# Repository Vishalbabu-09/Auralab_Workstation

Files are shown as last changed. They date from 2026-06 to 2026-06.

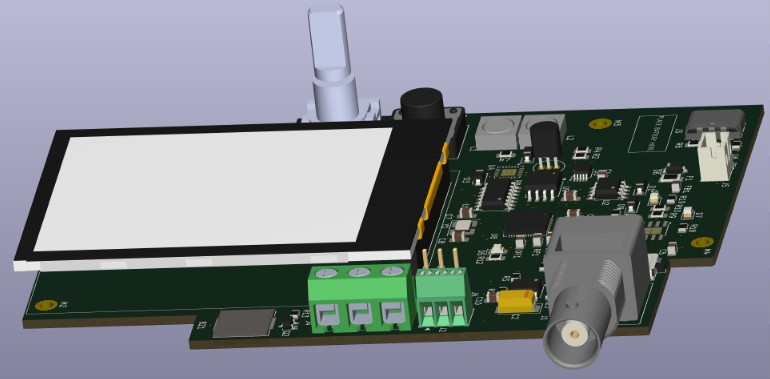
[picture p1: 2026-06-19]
Auralab_Workstation/Auralab_Workstation Images/Auralab Workstation 3D Sideview1.jpg

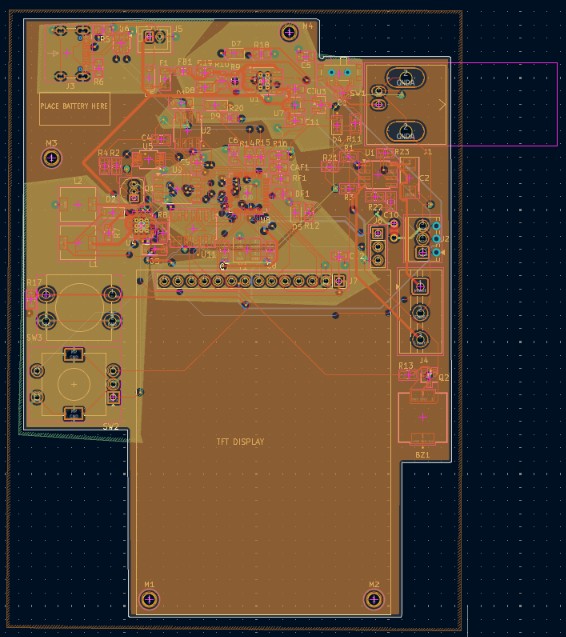
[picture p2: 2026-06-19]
Auralab_Workstation/Auralab_Workstation Images/4 Layers(F.Cu, In1.Cu, In2.Cu, B.CU).jpg

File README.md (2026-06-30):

# AURALAB WORKSTATION: Pocket-Sized Lab Bench & Hardware Diagnostic Toolkit

An advanced, ultra-portable multi-function test, measurement, and diagnostic platform engineered for the **KiCad PCB Design Contest**.

The **Auralab Workstation** packs a 12-bit digital oscilloscope, a variable bipolar $\pm15\text{V}$ bench power supply, an automated component curve tracer, and a smart hardware safety fault interrupter into a highly integrated, pocket-sized form factor.

---

## 1. System Working Modes & Operational Logic

The workstation utilizes the dual-core architecture of the **RP2040 microcontroller** to handle high-speed telemetry ingestion on one core while managing the graphical user interface (UI) and safety control loops on the second core.

### 📈 Mode 1: Oscilloscope Mode
* **What it does:** Captures, visualizes, and measures high-frequency external electrical signals in real time directly on the integrated 2.4" TFT display.
* **How it works:** Raw signals pass through an AC/DC coupling selector switch into a high-impedance **TL072 JFET operational amplifier** buffer circuit. This prevents the workstation from loading down the circuit under test. The conditioned signal is digitized by a dedicated **MCP3201 12-bit SAR ADC** operating over a high-speed SPI bus. Core 0 of the RP2040 processes the raw data arrays to compute signal parameters including **frequency, duty cycle, time period, $V_{pp}$ (peak-to-peak), and $V_{RMS}$**.

### ⚡ Mode 2: Bipolar DC Bench Power Supply Mode
* **What it does:** Acts as a precision-adjustable split-rail power supply delivering up to $\pm15\text{V}$ to drive external analog, op-amp, and prototype circuits via low-impedance screw terminals (`J2`).
* **How it works:** The user rotates the incremental digital encoder to set a target voltage. The RP2040 transmits this target via SPI to an **MCP42010 Dual Digital Potentiometer**. This digital pot dynamically alters the resistor feedback network of a high-efficiency **TPS65131 split-rail buck-boost regulator**, scaling the outputs symmetrically.

### 📊 Mode 3: Automated Component Curve Tracer Mode
* **What it does:** Plots the characteristic Voltage vs. Current ($V\text{-}I$) curves of un-biased two-terminal components (diodes, transistors, resistors, LEDs) directly onto the display to identify unknown parts or detect faulty silicon behavior.
* **How it works:** The workstation generates an internal hardware voltage sweep using a smoothed, high-frequency **Sweep PWM signal**. This low-pass filtered signal is amplified through a dedicated stage of the **TL072 op-amp**. As the voltage sweeps across the test terminal, an **INA219 high-side current monitor** reads the voltage drop across a $0.1\Omega$ shunt resistor, graphing the exact threshold voltages ($V_{th}$), saturation curves, and breakdown regions.

### 🛑 Mode 4: Smart Fault Detection & Overload Interrupter
* **What it does:** Acts as a real-time, hybrid hardware-software circuit breaker protecting both the workstation and your external device under test from short circuits, overcurrent conditions, and reverse polarity.
* **How it works:** The **INA219 current sensor** constantly monitors active current draw. If the current spikes past a safe user-defined ceiling, a hardware interrupt flag (`CURRENT_ALERT`) fires. The microcontroller instantly isolates the output terminals, flashes a high-intensity **ALERT_LED**, and triggers a resonant **Piezo Buzzer** to notify the user. Backup physical protection is maintained via an inline **Polyfuse (F1)** and steering clamping diodes.

---

## 2. Advanced 4-Layer PCB Stackup & Plane Allocation

To preserve 12-bit ADC accuracy while operating high-frequency digital clocks right next to high-gain analog buffers, this board utilizes a strict 4-layer mixed-signal stackup.

| Layer | Name | Copper Type | Main Signals & Plane Assignments |
| :--- | :--- | :--- | :--- |
| **Layer 1** | `F.Cu` (Top) | Signal / High-Speed | Component placement, SPI buses (Display, Flash, ADC), $\text{I}^2\text{C}$ lines, and sensitive analog trace lines. |
| **Layer 2** | `In1.Cu` | Split Ground Plane | **`GND` (Digital Ground Plane)** under the RP2040/Flash, and **`GNDA` (Analog Ground Plane)** under the Op-Amp/ADC/Reference. Isolated by a physical gap and joined strictly at a single point via a `NetTie_2` footprint near the power entrance. |
| **Layer 3** | `In2.Cu` | Dedicated Power Plane | Solid **`+3V3_DIGITAL`** power plane to provide clean, low-impedance power distribution across the digital logic core. |
| **Layer 4** | `B.Cu` (Bottom) | Signal Layer | Dedicated strictly to routing low-frequency control signals (Encoder pins, switch tracking lines) to keep them isolated from high-speed loops. |

---

## 3. Detailed Schematic & Hardware Architecture Breakdown

The hardware layout is organized into three highly optimized hierarchical sheets:

### 🔋 Module 1: Power Management & Filtration (Sheet 2)
Handles the regulation of raw input vectors, lithium-ion battery management, and high-current variable power rails.
* **USB-C Interface (`J3`):** Employs a 16-pin USB-C receptacle protected by an ultra-low capacitance **USBLC6-25C6 ESD array** to prevent electro-static damage across the differential lines.
* **BMS Stage (`U8`):** Uses a **TP4056 linear charger** with a precision $1.2\text{k}\Omega$ $R_{prog}$ resistor to regulate charging cycles safely for an attached Li-Po battery.
* **Split-Rail Engine (`U5`):** The **TPS65131 buck-boost converter** functions alongside high-current **SRR6048** power inductors ($L1, L2$) and high-speed Schottky catch diodes to cleanly establish the variable bipolar tracking rails.

### 🧠 Module 2: RP2040 Core & Interface Subsystem (Sheet 3)
Formulates the digital brain, memory maps, and human-machine interface routing.
* **Clocking Engine (`Y1`):** A low-jitter **12MHz Quartz Crystal** ensures ultra-stable operation for synchronous SPI data ingestion from the high-resolution ADC.
* **Storage Array (`U11`):** A **W25Q128JVS 128Mb QSPI Flash IC** stores custom GUI frames, display fonts, and analytical logging tables.

### 🔬 Module 3: Precision Analog Front-End (Sheet 4)
Handles conditioning, front-end buffering, clamping, and current telemetry tracking.
* **Precision Voltage Reference (`U3`):** Uses a low-drift **REF3033 bandgap voltage reference** to output a rock-solid, noise-free $3.3\text{V}$ absolute ceiling (`Vref_ADC`) directly to the SAR ADC, completely mitigating reference measurement drift.
* **Dynamic Range Shifter (`Q1`):** Features an automated hardware range shifter. By steering the gate of an **85170 N-Channel Power MOSFET**, the microcontroller alters the shunt resistor topology dynamically, switching scales between high-current tracking and micro-amp precision modes automatically.

---

## 4. Manufacturing & STEP Mechanical Export Validation

The project layout files have passed full Design Rule Checking (DRC) with 0 errors. A universal 3D mechanical master assembly model has been generated directly from the layout engine:

* **Export Format:** STEP (.step) standard mechanical vector.
* **Output Package Verified:** `Auralab_Workstation_Vishal.step` includes fully rendered 3D models for all high-profile custom footprints, including the 2.4" TFT module, the **XY126-3P** green terminal blocks, and the shielded **SRR6048** power inductors.
* **Compatibility:** Fully compliant with industry standard CAD software (SolidWorks, Autodesk Fusion 360, and free web viewers like `viewer.autodesk.com`).

---

## 5. Repository Directory Tree

```text
├── 3D Models Auralab_Workstation_Vishal/  <- Local STEP structural component cache
├── Auralab_Workstation Images/            <- Visual project logs and board renderings
├── Auralab_Workstation_Vishal schematic/  <- Schematic sheet files
├── Manufacturing/
│   ├── Drill/                             <- NC Drill files (.drl)
│   └── Gerbers/                           <- RS-274X Production plots (.gbr)
├── Auralab_Workstation_Vishal.kicad_pro   <- Master KiCad Project Hub File
├── Auralab_Workstation_Vishal.kicad_sch   <- Master Hierarchical Schematic Sheet
├── Auralab_Workstation_Vishal.kicad_pcb   <- Complete 4-Layer Routed PCB Layout
├── Auralab_Workstation_Vishal.pdf         <- Complete schematic printable export
└── LICENSE                                <- Open-source distribution documentation

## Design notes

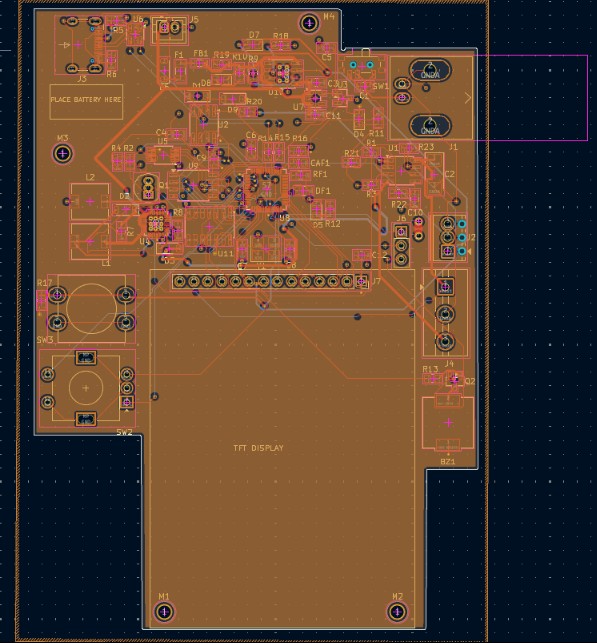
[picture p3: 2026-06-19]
Auralab_Workstation/Auralab_Workstation Images/Layer-3(In2.Cu) 3.3V digital plane.jpg

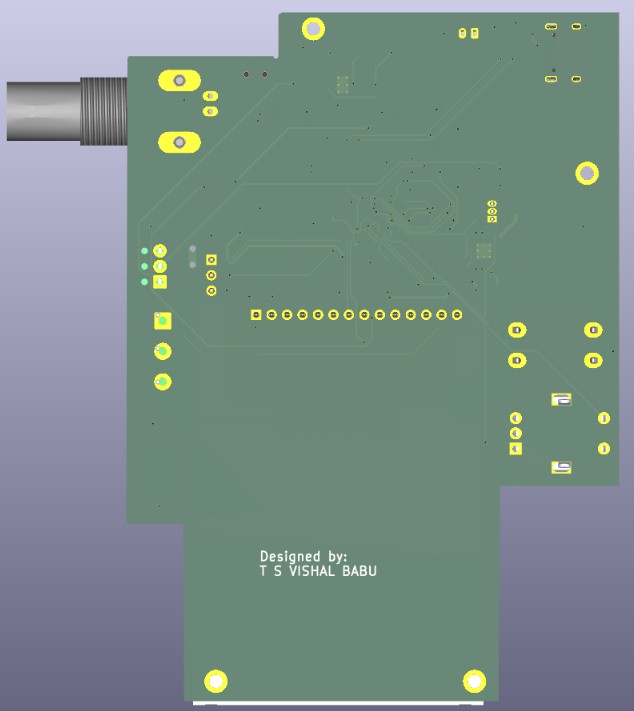
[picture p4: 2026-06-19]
Auralab_Workstation/Auralab_Workstation Images/Auralab Workstation 3D Bottomview.jpg

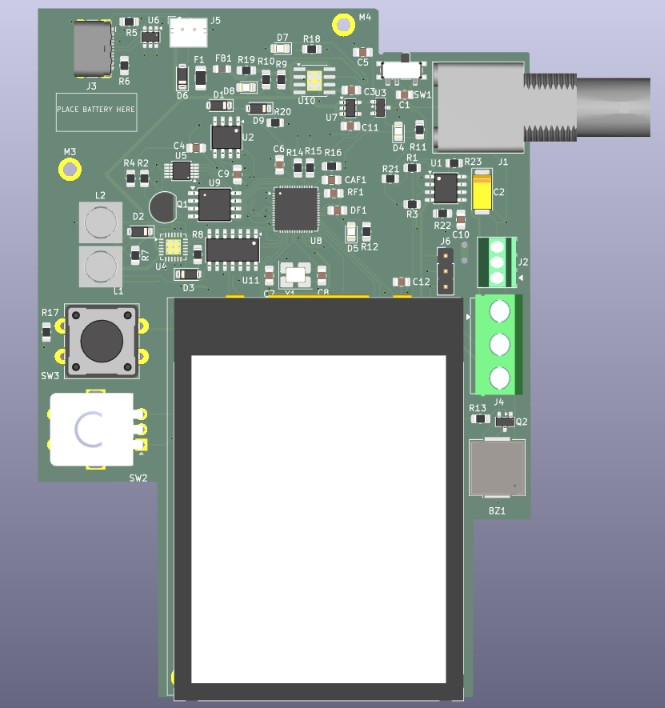
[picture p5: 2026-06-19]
Auralab_Workstation/Auralab_Workstation Images/Auralab Workstation 3D Topview.jpg

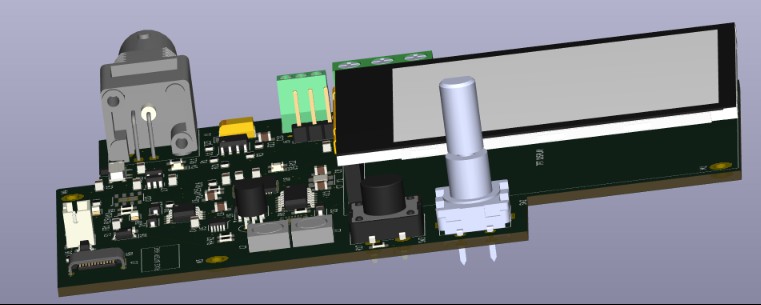
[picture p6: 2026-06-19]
Auralab_Workstation/Auralab_Workstation Images/Auralab Workstation 3D Sideview2.jpg

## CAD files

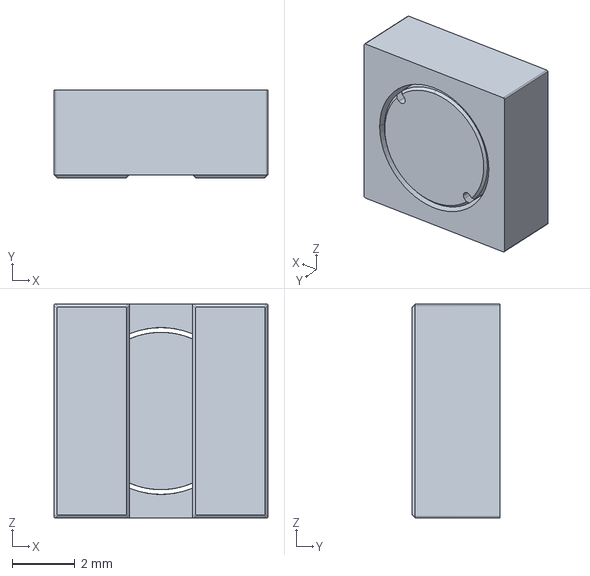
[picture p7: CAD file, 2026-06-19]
Auralab_Workstation/3D Models Auralab_Workstation_Vishal/Inductor.stp
6.80 x 2.80 x 6.80 mm

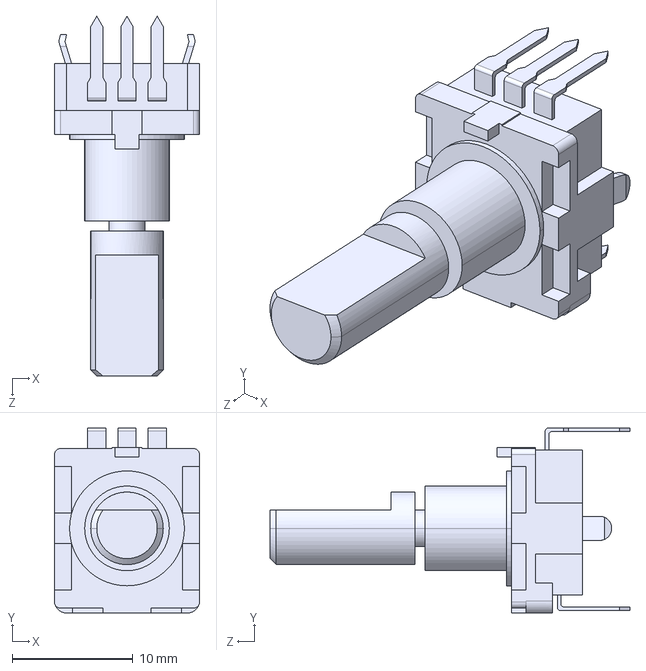
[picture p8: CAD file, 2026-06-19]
Auralab_Workstation/3D Models Auralab_Workstation_Vishal/Rotary Encoder switch.STEP
12.0 x 15.3 x 29.8 mm

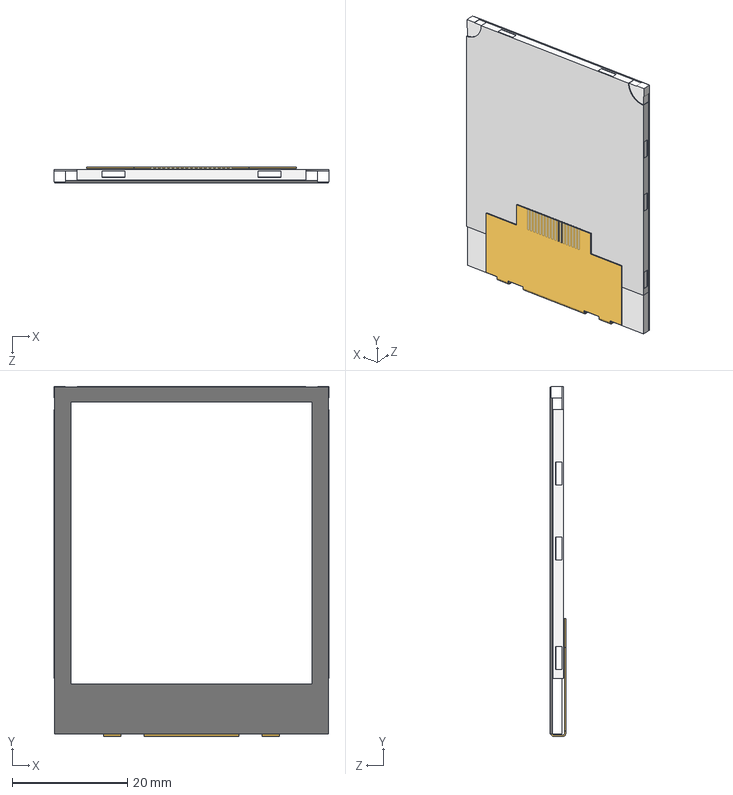
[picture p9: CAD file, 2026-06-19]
Auralab_Workstation/3D Models Auralab_Workstation_Vishal/TFTdisplay.STEP
47.7 x 60.7 x 2.75 mm

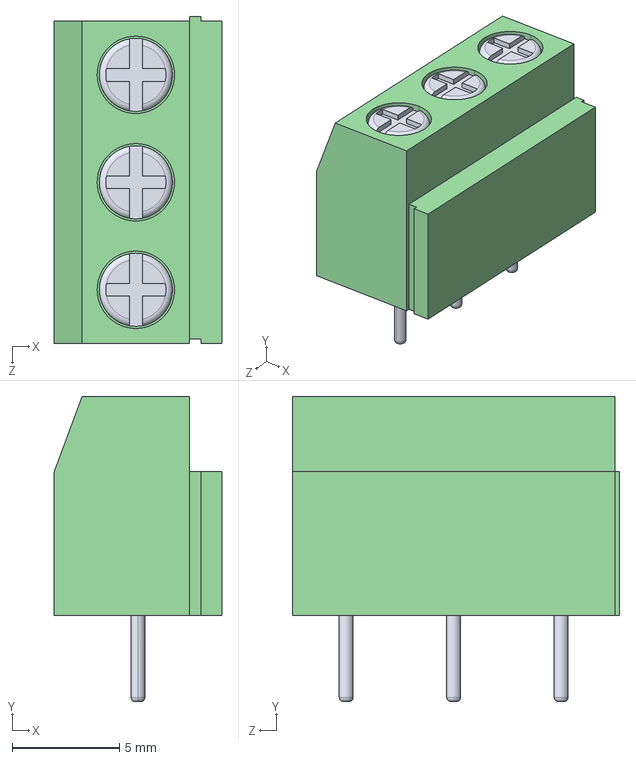
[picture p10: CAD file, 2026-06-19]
Auralab_Workstation/3D Models Auralab_Workstation_Vishal/3PinConnectorJ4.STEP
7.80 x 14.2 x 15.2 mm

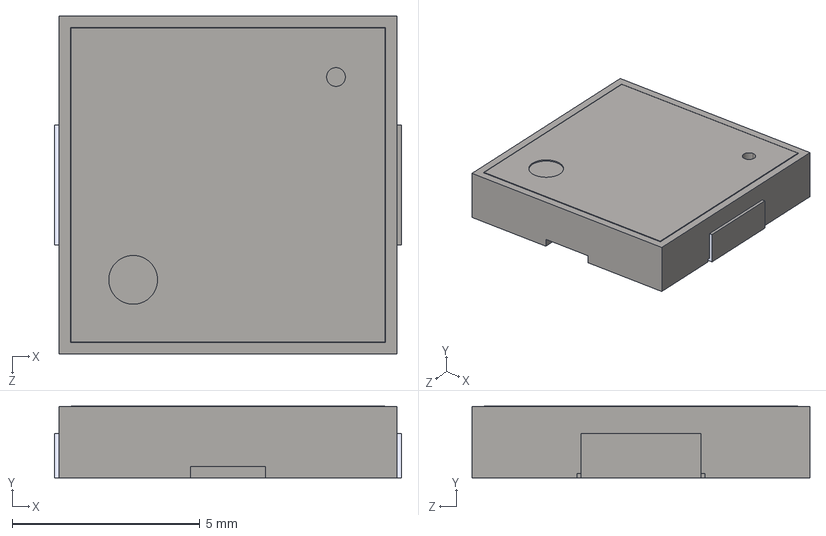
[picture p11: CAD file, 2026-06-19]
Auralab_Workstation/3D Models Auralab_Workstation_Vishal/Buzzer.step
9.24 x 1.91 x 9.00 mm

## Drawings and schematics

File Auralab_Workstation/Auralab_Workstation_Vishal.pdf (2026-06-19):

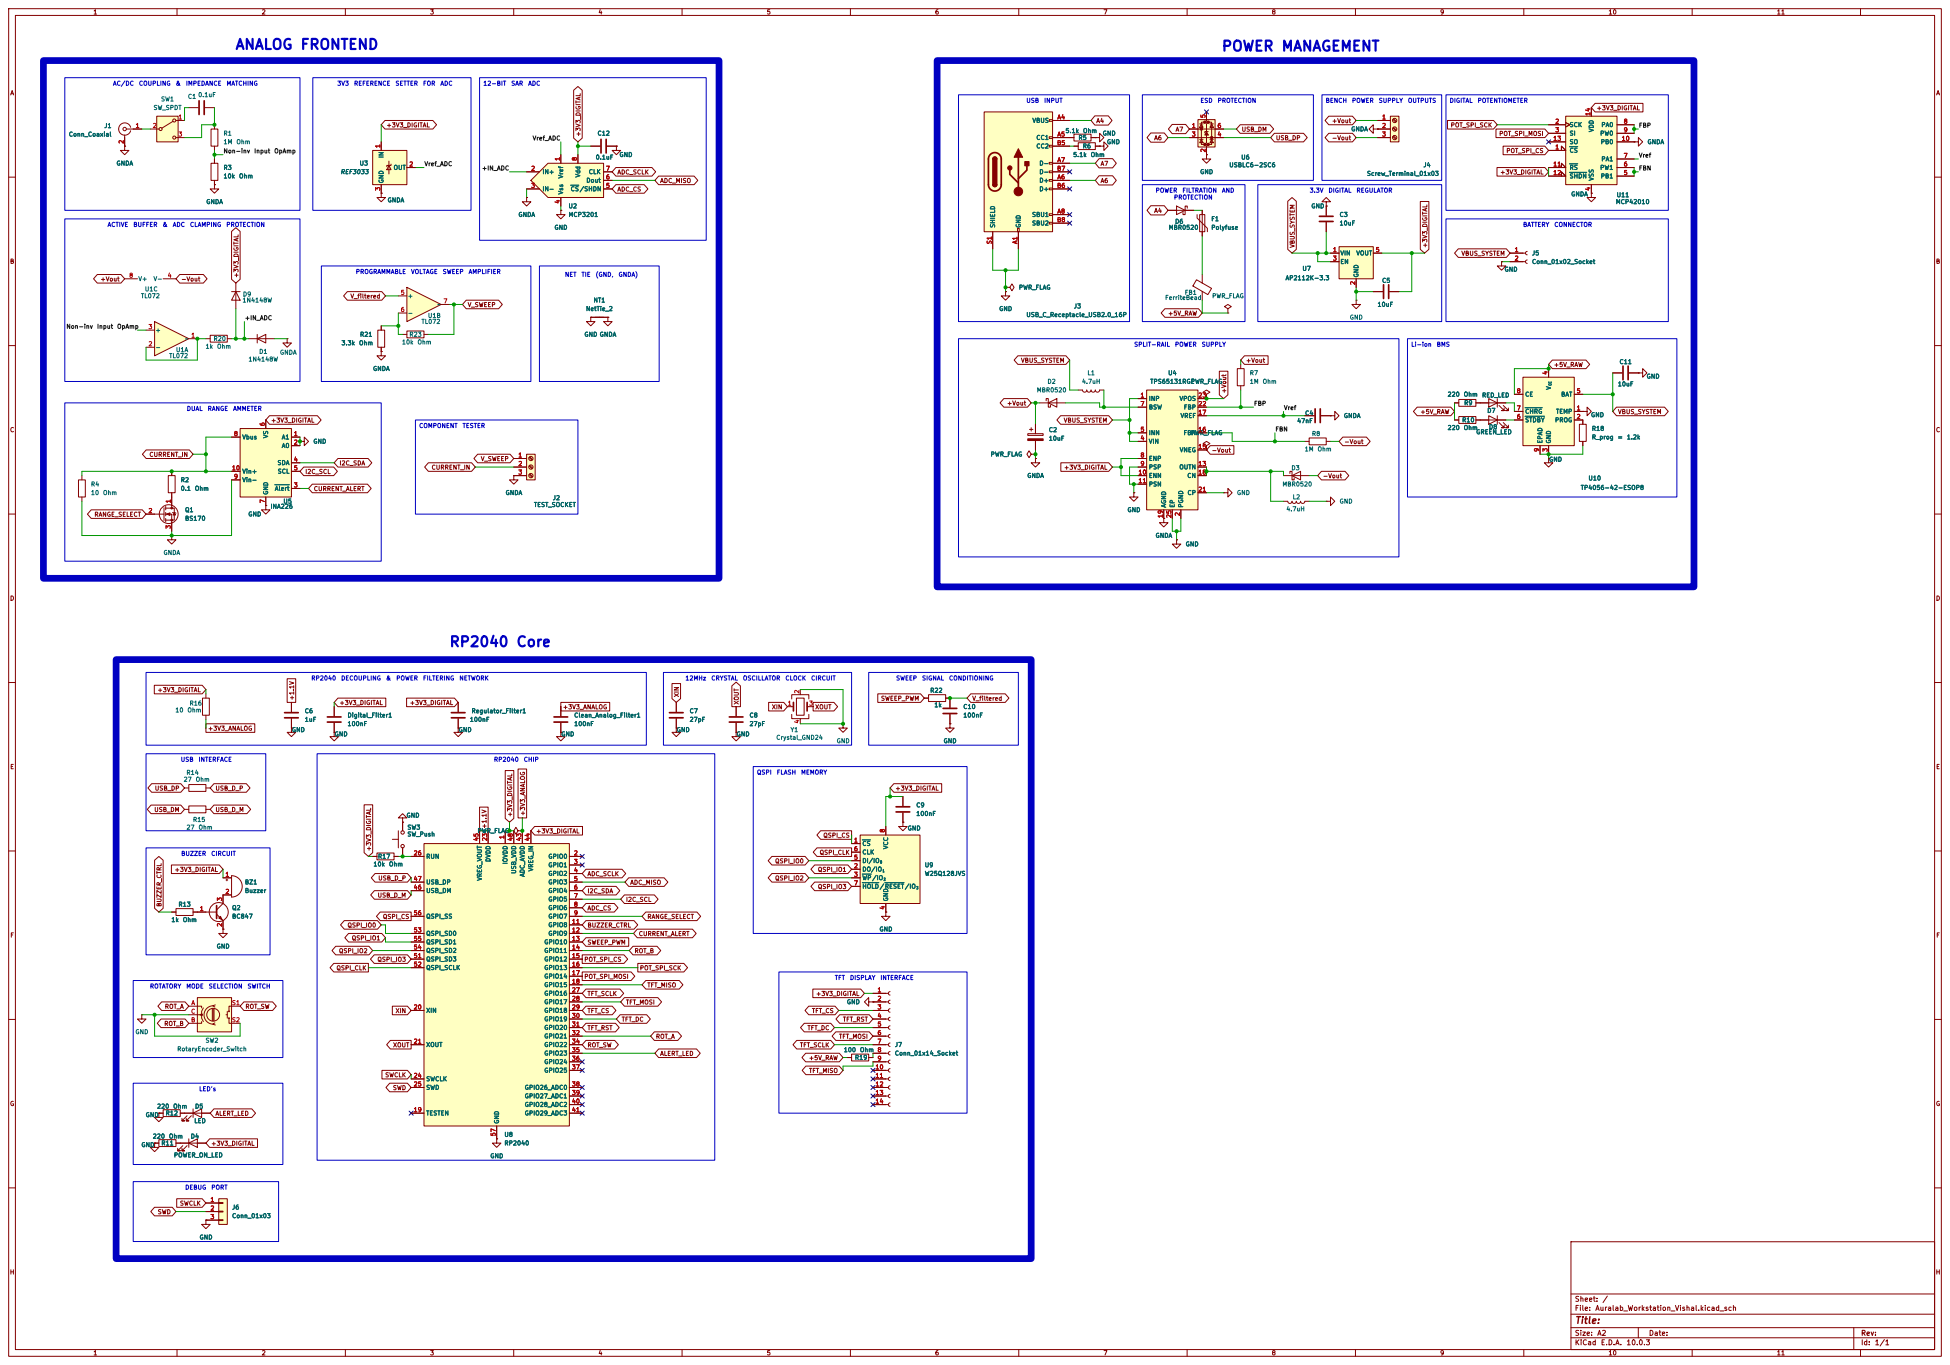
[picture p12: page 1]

ESD PROTECTION POWER MANAGEMENT

USB INPUT COMPONENT TESTER

BENCH POWER SUPPLY OUTPUTS
+3V3_DIGITAL -Vout

ACTIVE BUFFER & ADC CLAMPING PROTECTION

PROGRAMMABLE VOLTAGE SWEEP AMPLIFIER

NET TIE (GND, GNDA)

SPLIT-RAIL POWER SUPPLY SWEEP SIGNAL CONDITIONING

Li-ion BMS | C11

Vin- 9

12MHz CRYSTAL OSCILLATOR CLOCK CIRCUIT

4 DI/IO0 5 CLK 6 HOLD/RESET/IO3 7 VCC

ROTATORY MODE SELECTION SWITCH
TFT_RST +3V3_DIGITAL ROT_A

Size: A2 | Rev:
KiCad E.D.A. 10.0.3 | Id: 1/1

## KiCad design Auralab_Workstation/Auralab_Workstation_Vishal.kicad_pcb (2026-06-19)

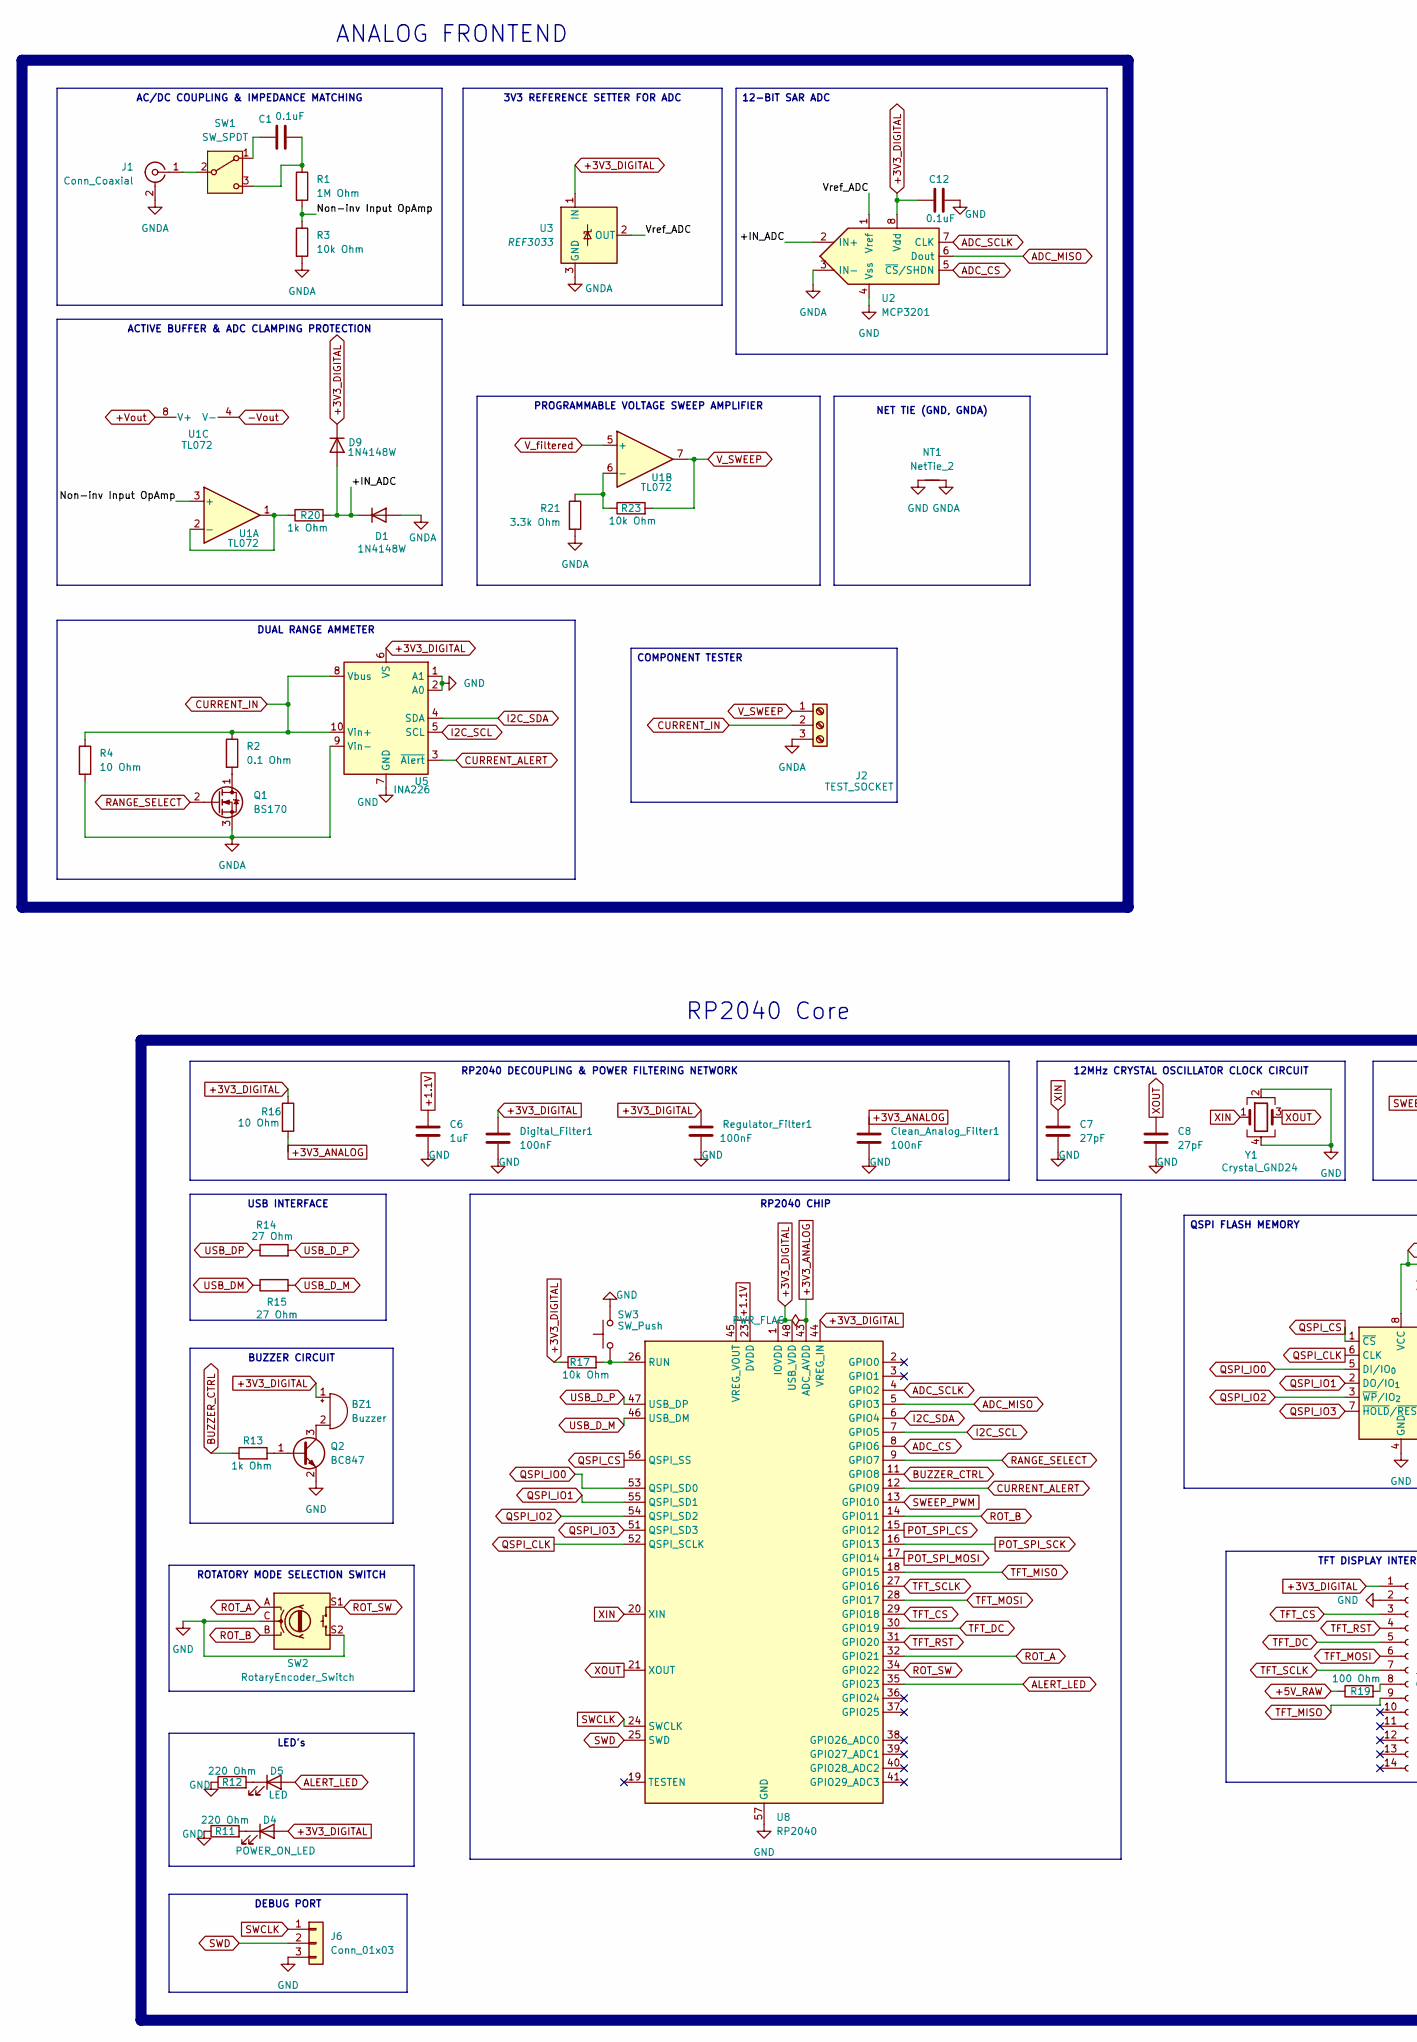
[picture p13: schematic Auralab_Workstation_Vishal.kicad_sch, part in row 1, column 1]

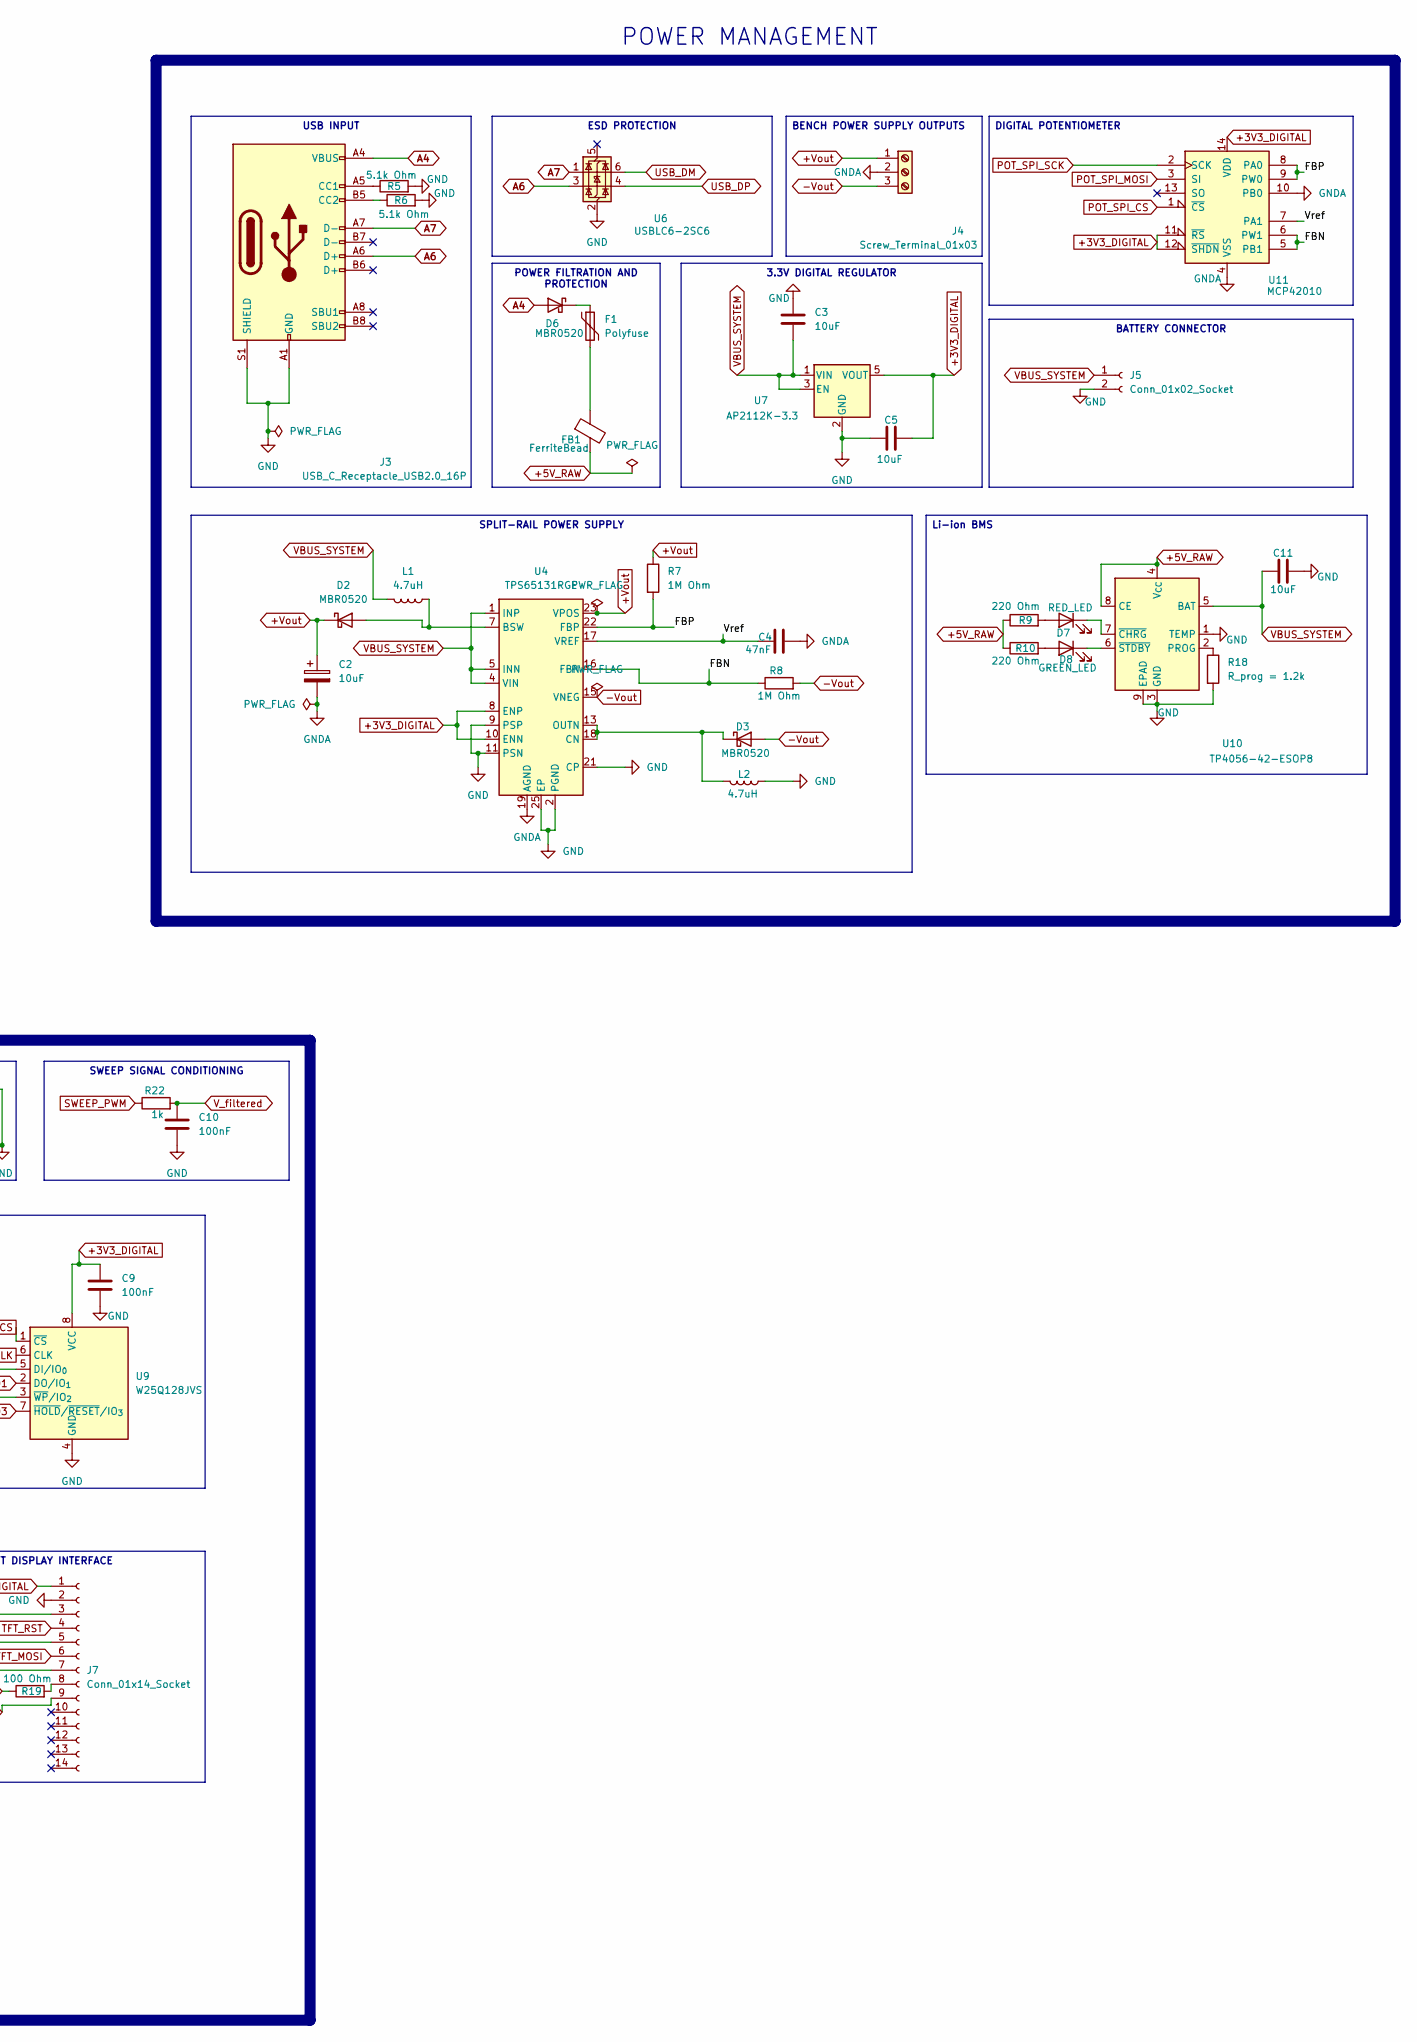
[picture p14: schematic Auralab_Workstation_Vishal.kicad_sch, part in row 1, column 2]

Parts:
BZ1: Buzzer; Buzzer_CUI_CPT-9019S-SMT
C1, C12: 0.1uF; C_0805_2012Metric
C2: 10uF; CP_EIA-6032-28_Kemet-C_HandSolder
C3, C5, C11: 10uF; C_0805_2012Metric_Pad1.18x1.45mm_HandSolder
C4: 47nF; C_0805_2012Metric_Pad1.18x1.45mm_HandSolder
C6: 1uF; C_0805_2012Metric_Pad1.18x1.45mm_HandSolder
C7, C8: 27pF; C_0805_2012Metric_Pad1.18x1.45mm_HandSolder
C9, C10: 100nF; C_0805_2012Metric_Pad1.18x1.45mm_HandSolder
Clean_Analog_Filter1: 100nF; C_0805_2012Metric_Pad1.18x1.45mm_HandSolder
D1, D9: 1N4148W; D_SOD-123
D2, D3, D6: MBR0520; D_SOD-123
D4: POWER_ON_LED; LED_0805_2012Metric_Pad1.15x1.40mm_HandSolder
D5: LED; LED_0805_2012Metric_Pad1.15x1.40mm_HandSolder
D7: RED_LED; LED_0805_2012Metric_Pad1.15x1.40mm_HandSolder
D8: GREEN_LED; LED_0805_2012Metric_Pad1.15x1.40mm_HandSolder
Digital_Filter1: 100nF; C_0805_2012Metric_Pad1.18x1.45mm_HandSolder
F1: Polyfuse; Fuse_1206_3216Metric
FB1: FerriteBead; L_0805_2012Metric
J1: Conn_Coaxial; BNC_Amphenol_B6252HB-NPP3G-50_Horizontal
J2: TEST_SOCKET; TerminalBlock_Phoenix_MPT-0,5-3-2.54_1x03_P2.54mm_Horizontal
J3: USB_C_Receptacle_USB2.0_16P; USB_C_Receptacle_HCTL_HC-TYPE-C-16P-01A
J4: Screw_Terminal_01x03; TerminalBlock_MaiXu_MX126-5.0-03P_1x03_P5.00mm
J5: Conn_01x02_Socket; JST_PH_B2B-PH-K_1x02_P2.00mm_Vertical
J6: Conn_01x03; PinHeader_1x03_P2.54mm_Vertical
J7: Conn_01x14_Socket; PinSocket_1x14_P2.54mm_Vertical
L1, L2: 4.7uH; L_6.3x6.3_H3
NT1: NetTie_2
Q1: BS170; TO-92_Inline
Q2: BC847; SOT-23
R1: 1M Ohm; R_0805_2012Metric
R2: 0.1 Ohm; R_0805_2012Metric
R3, R23: 10k Ohm; R_0805_2012Metric
R4: 10 Ohm; R_0805_2012Metric
R5, R6: 5.1k Ohm; R_0805_2012Metric_Pad1.20x1.40mm_HandSolder
R7, R8: 1M Ohm; R_0805_2012Metric_Pad1.20x1.40mm_HandSolder
R9, R10, R11, R12: 220 Ohm; R_0805_2012Metric_Pad1.20x1.40mm_HandSolder
R13: 1k Ohm; R_0805_2012Metric_Pad1.20x1.40mm_HandSolder
R14, R15: 27 Ohm; R_0805_2012Metric_Pad1.20x1.40mm_HandSolder
R16: 10 Ohm; R_0805_2012Metric_Pad1.20x1.40mm_HandSolder
R17: 10k Ohm; R_0805_2012Metric_Pad1.20x1.40mm_HandSolder
R18: R_prog = 1.2k; R_0805_2012Metric_Pad1.20x1.40mm_HandSolder
R19: 100 Ohm; R_0805_2012Metric_Pad1.20x1.40mm_HandSolder
R20: 1k Ohm; R_0805_2012Metric
R21: 3.3k Ohm; R_0805_2012Metric
R22: 1k; R_0805_2012Metric_Pad1.20x1.40mm_HandSolder
Regulator_Filter1: 100nF; C_0805_2012Metric_Pad1.18x1.45mm_HandSolder
SW1: SW_SPDT; SW_SPDT_PCM12
SW2: RotaryEncoder_Switch; RotaryEncoder_Alps_EC11E-Switch_Vertical_H20mm
SW3: SW_Push; SW_PUSH-12mm_Wuerth-430476085716
U1: TL072; SOIC-8_3.9x4.9mm_P1.27mm
U2: MCP3201; SOIC-8_3.9x4.9mm_P1.27mm
U3: REF3033; SOT-23
U4: TPS65131RGE; VQFN-24-1EP_4x4mm_P0.5mm_EP2.45x2.45mm_ThermalVias
U5: INA226; MSOP-10_3x3mm_P0.5mm
U6: USBLC6-2SC6; SOT-23-6
U7: AP2112K-3.3; SOT-23-5
U8: RP2040; QFN-56-1EP_7x7mm_P0.4mm_EP3.2x3.2mm
U9: W25Q128JVS; SOIC-8_5.3x5.3mm_P1.27mm
U10: TP4056-42-ESOP8; SOIC-8-1EP_3.9x4.9mm_P1.27mm_EP2.41x3.3mm_ThermalVias
U11: MCP42010; SOIC-14_3.9x8.7mm_P1.27mm
Y1: Crystal_GND24; Crystal_SMD_3225-4Pin_3.2x2.5mm_HandSoldering

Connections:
+1.1V: C6.1, U8.23 (DVDD), U8.45 (VREG_VOUT), U8.50 (DVDD)
+3V3_ANALOG: Clean_Analog_Filter1.1, R16.2, U8.43 (ADC_AVDD); also elsewhere on the board
+3V3_DIGITAL: BZ1.1 (+), C5.1, C9.1, C12.1, D4.2 (A), D9.1 (K), Digital_Filter1.1, J7.1, R16.1, R17.1, Regulator_Filter1.1, U2.8 (Vdd), U3.1 (IN), U4.8 (ENP), U4.10 (ENN), U5.6 (VS), U7.5 (VOUT), U8.1 (IOVDD), U8.10 (IOVDD), U8.22 (IOVDD), U8.33 (IOVDD), U8.42 (IOVDD), U8.44 (VREG_IN), U8.48 (USB_VDD), U8.49 (IOVDD), U9.8 (VCC), U11.11 (~RS), U11.12 (~SHDN), U11.14 (VDD); also elsewhere on the board
+5V_RAW: FB1.2, R9.1, R10.1, R19.1, U10.4 (V_{CC}), U10.8 (CE)
+Vout: C2.1, D2.1 (K), J4.1, R7.1, U1.8 (V+), U4.23 (VPOS)
-Vout: D3.2 (A), J4.3, R8.2, U1.4 (V-), U4.15 (VNEG)
/+IN_ADC: D1.1 (K), D9.2 (A), R20.2, U2.2 (IN+)
/FBN: R8.1, U4.16 (FBN), U11.5 (PB1), U11.6 (PW1)
/FBP: R7.2, U4.22 (FBP), U11.8 (PA0), U11.9 (PW0)
/Non-inv Input OpAmp: R1.2, R3.1, U1.3 (+)
/Vref: C4.1, U4.17 (VREF), U11.7 (PA1)
/Vref_ADC: U2.1 (Vref), U3.2 (OUT)
A4: D6.2 (A), J3.A4 (VBUS), J3.A9 (VBUS), J3.B4 (VBUS), J3.B9 (VBUS)
A6: J3.A6 (D+), U6.3 (I/O2)
A7: J3.A7 (D-), U6.1 (I/O1)
ADC_CS: U2.5 (~CS/SHDN), U8.8 (GPIO6)
ADC_MISO: U2.6 (Dout), U8.5 (GPIO3)
ADC_SCLK: U2.7 (CLK), U8.4 (GPIO2)
ALERT_LED: D5.2 (A), U8.35 (GPIO23)
BUZZER_CTRL: R13.1, U8.11 (GPIO8)
CURRENT_ALERT: U5.3 (~Alert), U8.12 (GPIO9)
CURRENT_IN: J2.2, R2.1, R4.1, U5.8 (Vbus), U5.10 (Vin+)
GND: C3.1, C5.2, C6.2, C7.2, C8.2, C9.2, C10.2, C11.2, C12.2, Clean_Analog_Filter1.2, Digital_Filter1.2, J3.A1 (GND), J3.A12 (GND), J3.B1 (GND), J3.B12 (GND), J3.S1 (SHIELD), J3.SH, J5.2, J6.3, J7.2, L2.1, NT1.1, Q2.2 (E), R5.2, R6.2, R11.1, R12.1, R18.2, Regulator_Filter1.2, SW2.C, SW2.MP, SW2.S2, SW3.2, U2.4 (Vss), U4.2 (PGND), U4.3 (PGND), U4.9 (PSP), U4.11 (PSN), U4.21 (CP), U4.25 (EP), U5.1 (A1), U5.2 (A0), U5.7 (GND), U6.2 (GND), U7.2 (GND), U8.57 (GND), U9.4 (GND), U10.1 (TEMP), U10.3 (GND), U10.9 (EPAD), Y1.2, Y1.4; also elsewhere on the board
GNDA: C2.2, C4.2, D1.2 (A), J1.2 (Ext), J2.3, J4.2, NT1.2, Q1.3 (S), R3.2, R4.2, R21.2, U2.3 (IN-), U3.3 (GND), U4.19 (AGND), U5.9 (Vin-), U11.4 (VSS), U11.10 (PB0)
I2C_SCL: U5.5 (SCL), U8.7 (GPIO5)
I2C_SDA: U5.4 (SDA), U8.6 (GPIO4)
unnamed: BZ1.2 (-), Q2.3 (C)
unnamed: D2.2 (A), L1.1, U4.7 (BSW)
unnamed: D3.1 (K), L2.2, U4.13 (OUTN), U4.14 (OUTN), U4.18 (CN)
unnamed: D4.1 (K), R11.2
unnamed: D5.1 (K), R12.2
unnamed: D6.1 (K), F1.1
unnamed: D7.2 (A), R9.2
unnamed: D7.1 (K), U10.7 (~CHRG)
unnamed: D8.2 (A), R10.2
unnamed: D8.1 (K), U10.6 (~STDBY)
unnamed: F1.2, FB1.1
unnamed: J1.1 (In), SW1.2 (B)
unnamed: J3.A5 (CC1), R5.1
unnamed: J3.B5 (CC2), R6.1
unnamed: J7.8, R19.2
unnamed: Q1.1 (D), R2.2
unnamed: Q2.1 (B), R13.2
unnamed: C1.1, SW1.1 (A)
unnamed: C1.2, R1.1, SW1.3 (C)
unnamed: R20.1, U1.1, U1.2 (-)
unnamed: R21.1, R23.1, U1.6 (-)
unnamed: R17.2, SW3.1, U8.26 (RUN)
unnamed: R18.1, U10.2 (PROG)
POT_SPI_CS: U8.15 (GPIO12), U11.1 (~CS)
POT_SPI_MOSI: U8.17 (GPIO14), U11.3 (SI)
POT_SPI_SCK: U8.16 (GPIO13), U11.2 (SCK)
QSPI_CLK: U8.52 (QSPI_SCLK), U9.6 (CLK)
QSPI_CS: U8.56 (QSPI_SS), U9.1 (~CS)
QSPI_IO0: U8.53 (QSPI_SD0), U9.5 (DI/IO_{0})
QSPI_IO1: U8.55 (QSPI_SD1), U9.2 (DO/IO_{1})
QSPI_IO2: U8.54 (QSPI_SD2), U9.3 (~WP/IO_{2})
QSPI_IO3: U8.51 (QSPI_SD3), U9.7 (~HOLD/~RESET/IO_{3})
RANGE_SELECT: Q1.2 (G), U8.9 (GPIO7)
ROT_A: SW2.A, U8.32 (GPIO21)
ROT_B: SW2.B, U8.14 (GPIO11)
ROT_SW: SW2.S1, U8.34 (GPIO22)
SWCLK: J6.1, U8.24 (SWCLK)
SWD: J6.2, U8.25 (SWD)
SWEEP_PWM: R22.1, U8.13 (GPIO10)
TFT_CS: J7.3, U8.29 (GPIO18)
TFT_DC: J7.5, U8.30 (GPIO19)
TFT_MISO: J7.9, U8.18 (GPIO15)
TFT_MOSI: J7.6, U8.28 (GPIO17)
TFT_RST: J7.4, U8.31 (GPIO20)
TFT_SCLK: J7.7, U8.27 (GPIO16)
USB_DM: R15.1, U6.6 (I/O1)
USB_DP: R14.1, U6.4 (I/O2)
USB_D_M: R15.2, U8.46 (USB_DM)
USB_D_P: R14.2, U8.47 (USB_DP)
VBUS_SYSTEM: C3.2, C11.1, J5.1, L1.2, U4.1 (INP), U4.4 (VIN), U4.5 (INN), U4.6 (INN), U4.24 (INP), U7.1 (VIN), U7.3 (EN), U10.5 (BAT)
V_SWEEP: J2.1, R23.2, U1.7
V_filtered: C10.1, R22.2, U1.5 (+)
XIN: C7.1, U8.20 (XIN), Y1.1
XOUT: C8.1, U8.21 (XOUT), Y1.3

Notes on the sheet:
POWER MANAGEMENT
RP2040 Core
NET TIE (GND, GNDA)
ANALOG FRONTEND
3.3V DIGITAL REGULATOR
ROTATORY MODE SELECTION SWITCH
DEBUG PORT
3V3 REFERENCE SETTER FOR ADC
SPLIT-RAIL POWER SUPPLY
RP2040 DECOUPLING & POWER FILTERING NETWORK
COMPONENT TESTER
ESD PROTECTION
PROGRAMMABLE VOLTAGE SWEEP AMPLIFIER
SWEEP SIGNAL CONDITIONING
LED's
12MHz CRYSTAL OSCILLATOR CLOCK CIRCUIT
BUZZER CIRCUIT
Li-ion BMS
12-BIT SAR ADC
USB INPUT
ACTIVE BUFFER & ADC CLAMPING PROTECTION
USB INTERFACE
TFT DISPLAY INTERFACE
RP2040 CHIP
BENCH POWER SUPPLY OUTPUTS
POWER FILTRATION AND PROTECTION
BATTERY CONNECTOR
QSPI FLASH MEMORY
DIGITAL POTENTIOMETER
AC/DC COUPLING & IMPEDANCE MATCHING
DUAL RANGE AMMETER

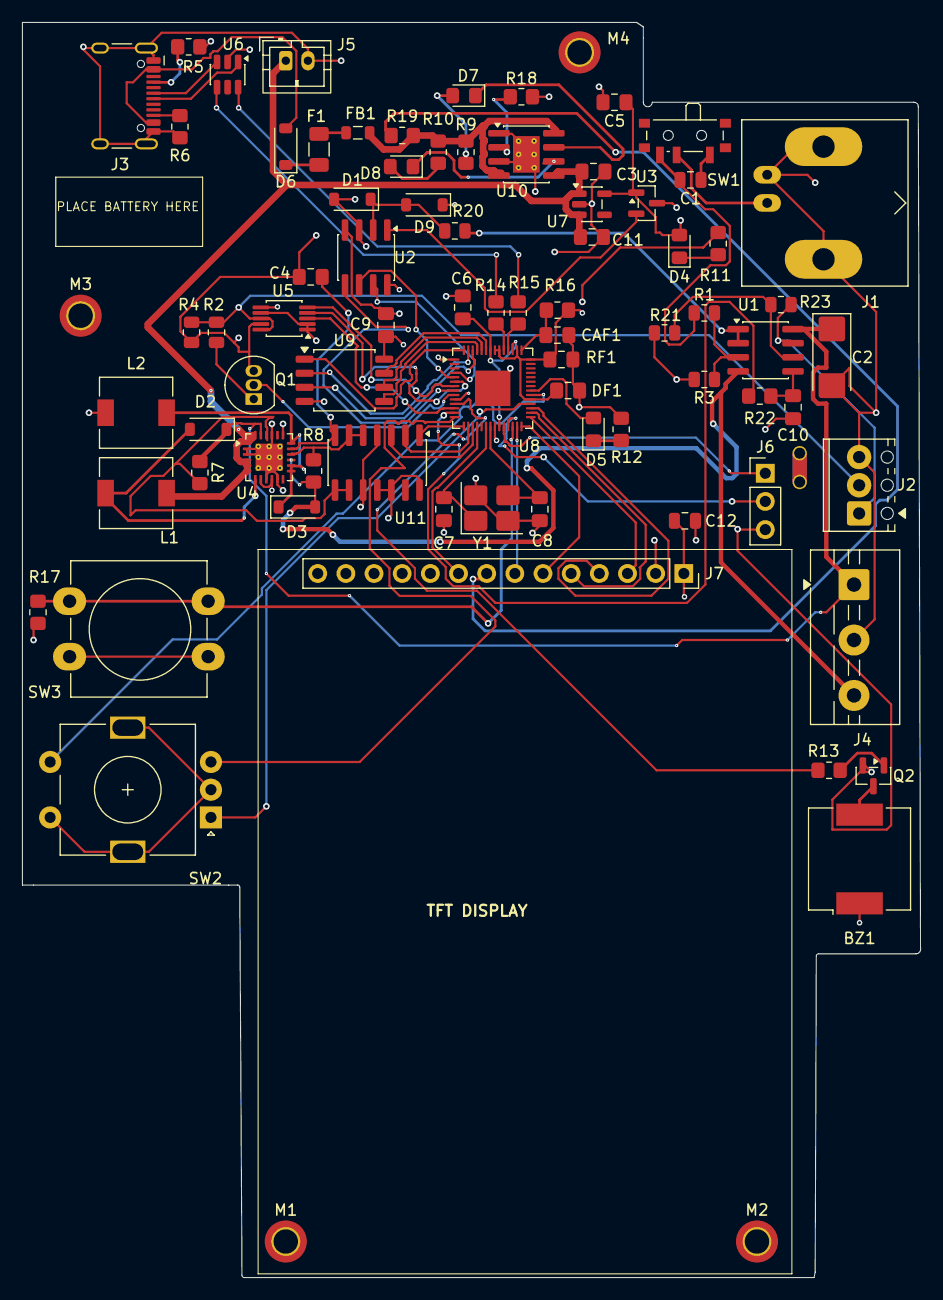
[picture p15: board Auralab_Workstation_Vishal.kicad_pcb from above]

Board: 4 copper layers, 81.0 x 113.2 mm, 81 parts (0 on the bottom side), 80 nets.

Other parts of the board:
CAF1: 100nF; C_0805_2012Metric_Pad1.18x1.45mm_HandSolder
DF1: 100nF; C_0805_2012Metric_Pad1.18x1.45mm_HandSolder
M1, M2, M3, M4: MountingHole_2.2mm_M2_DIN965_Pad_TopBottom
RF1: 100nF; C_0805_2012Metric_Pad1.18x1.45mm_HandSolder

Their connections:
+3V3_ANALOG: CAF1.1; also elsewhere on the board
+3V3_DIGITAL: DF1.1, RF1.1; also elsewhere on the board
GND: CAF1.2, DF1.2, RF1.2; also elsewhere on the board

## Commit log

2026-06-05 Initial KiCad Architecture Layout
    [Auralab_Workstation.kicad_pcb, Auralab_Workstation.kicad_sch, analog_front_end.kicad_sch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]
2026-06-06 started with connectionns
    [rp2040_core.kicad_sch]
2026-06-06 just rotated one net label in ur sch
    [pcbwaycontest.kicad_sch, rp2040_core.kicad_sch]
2026-06-06 oralavu panirken rp2040, nect un connections and mine sekanom that i will do tmrw
    [rp2040_core.kicad_sch]
2026-06-07 I almost completed my part ig
    [rp2040_core.kicad_sch]
2026-06-07 Made changes
    [pcbwaycontest.kicad_sch, rp2040_core.kicad_sch]
2026-06-07 Now updated..
    [rp2040_core.kicad_sch]
2026-06-07 Made few changes in IN2A66 in urs
    [pcbwaycontest.kicad_sch, rp2040_core.kicad_sch]
2026-06-07 Updated few in ur sch
    [pcbwaycontest.kicad_sch]
2026-06-08 Finished power management connections IG
    [power_management.kicad_sch]
2026-06-09 Deleted pcbway(1)
    [pcbwaycontest (1).kicad_sch]
2026-06-11 Updated gnd, gnda in analog_frontend
    [pcbwaycontest (4).kicad_sch]
2026-06-12 Updated footprints for rp2040
    [rp2040_core.kicad_sch]
2026-06-12 Power kum footprints added
    [power_management.kicad_sch]
2026-06-12 Power management le few changes made inum full ah complete panle..
    [power_management.kicad_sch, rp2040_core.kicad_sch]
2026-06-13 Power management connections checked its perfect now
    [power_management.kicad_sch, rp2040_core.kicad_sch]
2026-06-14 Check analog part
    [pcbwaycontest (4).kicad_sch, rp2040_core.kicad_sch]
2026-06-14 Check ERC
    [Auralab_Workstation.kicad_sch, analog_frontend.kicad_sch, pcbwaycontest (4).kicad_sch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]
2026-06-14 ERC checked
    [analog_frontend.kicad_sch, power_management.kicad_sch, rp2040_core.kicad_sch]
2026-06-14 uPDATED AURALAB workstation
    [Auralab_Workstation.kicad_sch]
2026-06-14 working schematic
2026-06-15 Auralab_1 is updated copy
    [AuralabWorkstation_1.kicad_pcb, maincontestpcb_vishal.kicad_pcb]
2026-06-16 removed unnecessary files
    [AuralabWorkstation_1.kicad_pcb, AuralabWorkstation_1.recovered.2026-06-15_192352.kicad_pcb, Auralab_Workstation.kicad_pcb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]
2026-06-16 Made few changes check
    [Auralab_Workstation.kicad_pcb, Auralab_Workstation.kicad_sch, maincontest.kicad_pcb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]
2026-06-16 renamed our old file as maincontest.kicadpcb
    [maincontest.kicad_pcb]
2026-06-19 Uploaded da..check
    [Auralab_Workstation_Vishal.kicad_pcb]
2026-06-19 Uploaded Gerber,Drill files
    [Auralab_Workstation_Vishal-B_Cu.gbr, Auralab_Workstation_Vishal-B_Mask.gbr, Auralab_Workstation_Vishal-B_Paste.gbr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]
